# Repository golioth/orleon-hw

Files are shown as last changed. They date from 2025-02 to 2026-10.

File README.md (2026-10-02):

# Orleon

A small round battery-powered Bluetooth LE sensor board from Golioth, built
around the Nordic nRF52840 in WLCSP. Rev A.

Orleon was designed as part of Golioth's "Designing and Building an AirTag
Clone" webinar series (April 2025):
https://blog.golioth.io/designing-and-building-an-airtag-clone-a-new-series-from-golioth/

> **Status:** pre-release cleanup for open-hardware (OSHW) publication.
> Items marked **[UNKNOWN]** need confirmation before this README is final.

## Hardware summary (Rev A)

| Subsystem | Part / details | Notes |
|---|---|---|
| Main SoC  | Nordic nRF52840-CKAA-F-R | WLCSP package |
| IMU | ST LIS2DH12 | 3-axis accelerometer, I2C |
| Microphone| ST MP34DT05TR-A | PDM MEMS mic |
| Audio out | Raltron RDTE-4.000-3030-NS1 | electromagnetic transducer (buzzer) |
| BLE antenna | Taoglas WLA.04 | 2.4 GHz chip antenna |
| NFC | Taoglas FXC.24.A flex antenna | |
| Battery | CR2032 coin cell (HF1N holder) | |
| Board | round, ~22 mm diameter | [UNKNOWN] confirm exact diameter |

## Hardware status (Rev A)

Rev A was manufactured by JLCPCB but **never fully validated**. Two issues
were found before the design was set aside:

1. **BGA copper pour.** The copper fill under the nRF52840 WLCSP was filled
   improperly at the fab. Recommended rework: remove the copper pour under
   the BGA entirely and instead place vias on each ball down to the ground
   layer.
2. **Buttons.** The side-firing button style was not a good fit for this
   form factor.

**This design was superseded by [Phial](https://github.com/golioth/phial-hw)**
(nRF54L15 + nPM2100), which is the better starting point for new work —
though note that Phial has its own validation issues (see that repo's README
for current status).

## Design files

- KiCad 9 project (`orleon.*`).
- JLCPCB was used for Rev A fabrication; commit history notes their 3.5 mil
  trace/space clearance constraint drove via/pad rework (see commit
  `cd74782`).
- `input/` — local symbol/footprint/3D sources and reference art.
- `orleon.pretty/` — project footprints (including Golioth and Orleon logo art
  footprints).

## Manufacturing outputs

**[UNKNOWN / TODO]** Rev A gerber packages (`orleon-a-*.zip`) were generated
for JLCPCB but never committed (gitignored). A fabrication package (gerbers,
drill, pick-and-place, BOM, schematic PDF) should be attached to a GitHub
Release before publication.

## Firmware

Firmware lives in a separate repo: [golioth/orleon-fw](https://github.com/golioth/orleon-fw)
(currently private).

## License

Hardware in this repository is released under the **CERN Open Hardware
Licence v2 — Permissive (CERN-OHL-P)**. See [LICENSE](LICENSE).

Note: `input/art/` contains vendor reference images (JLCPCB stackup, Taoglas
antenna drawings) that are **not** covered by this license and may be replaced
with links before publication.

## Credits

Designed by Chris Gammell at Golioth.

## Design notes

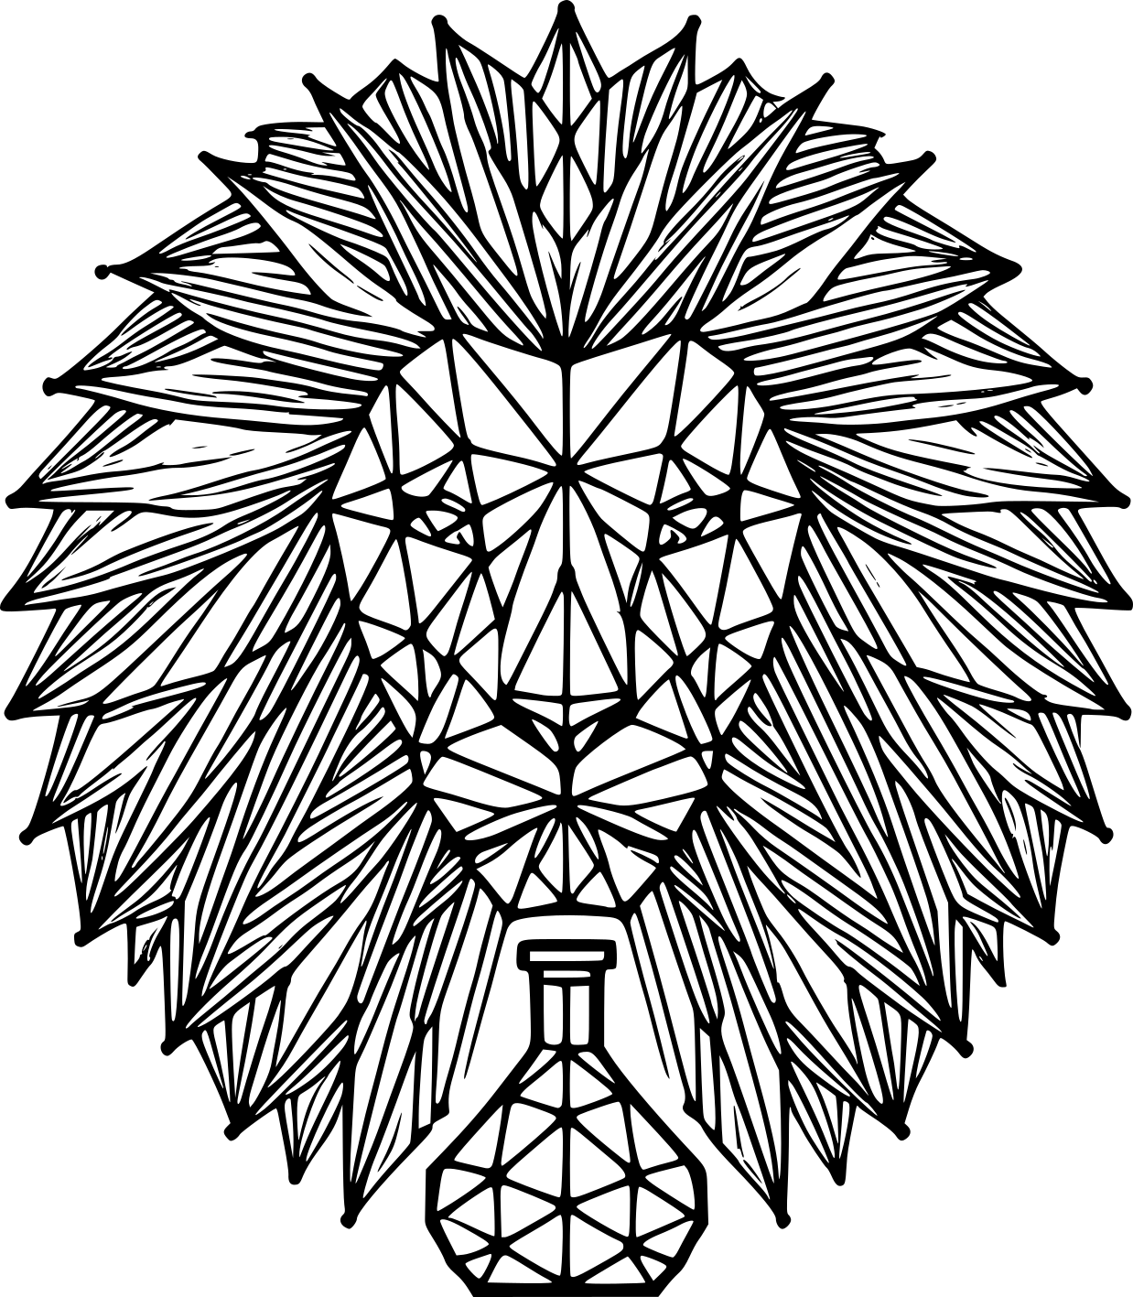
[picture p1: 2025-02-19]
input/art/orleon_36mm.png

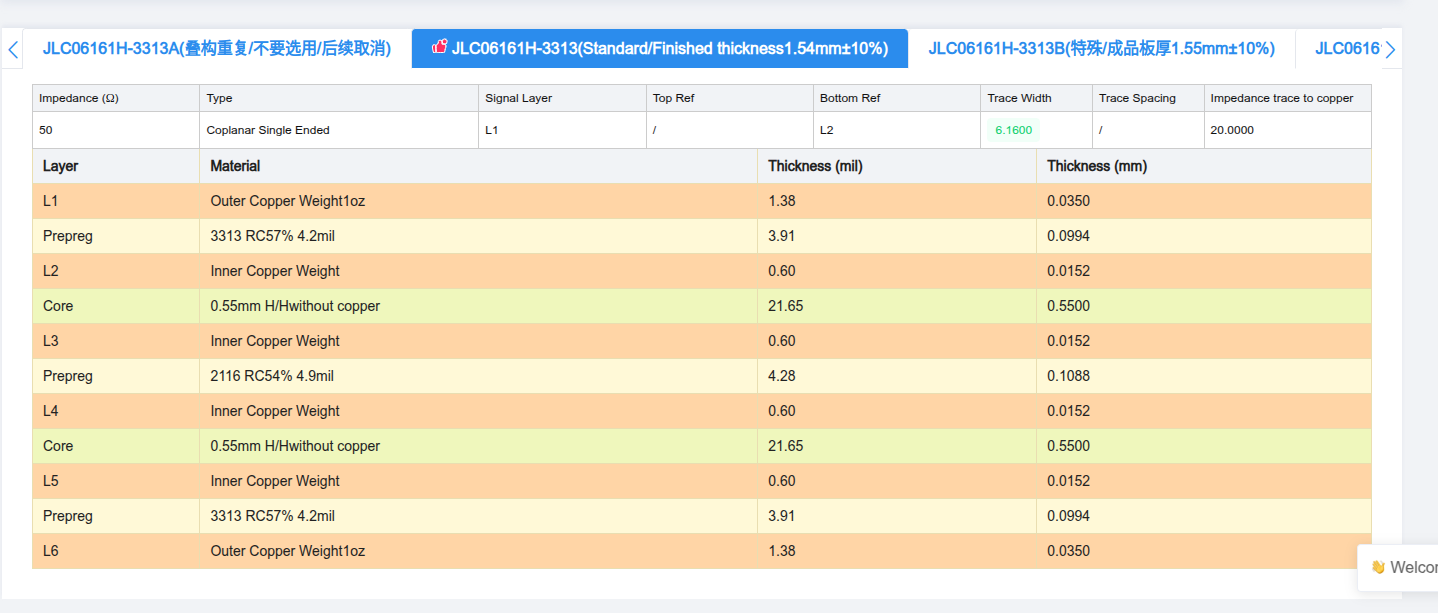
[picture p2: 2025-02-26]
input/art/JLC-0616.png

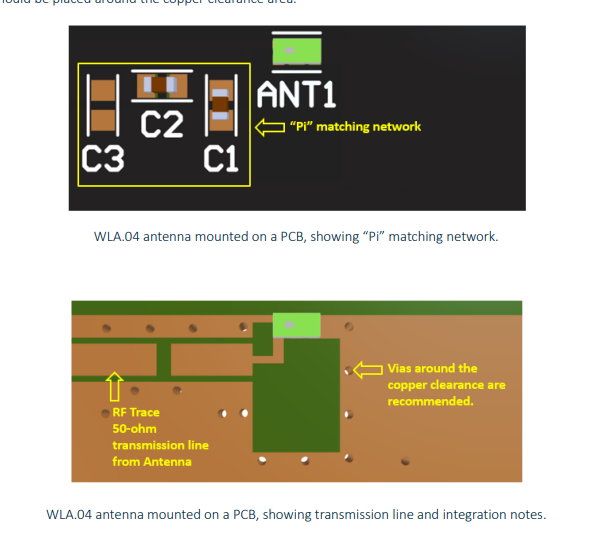
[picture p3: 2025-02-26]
input/art/WLA-04-Layout.png

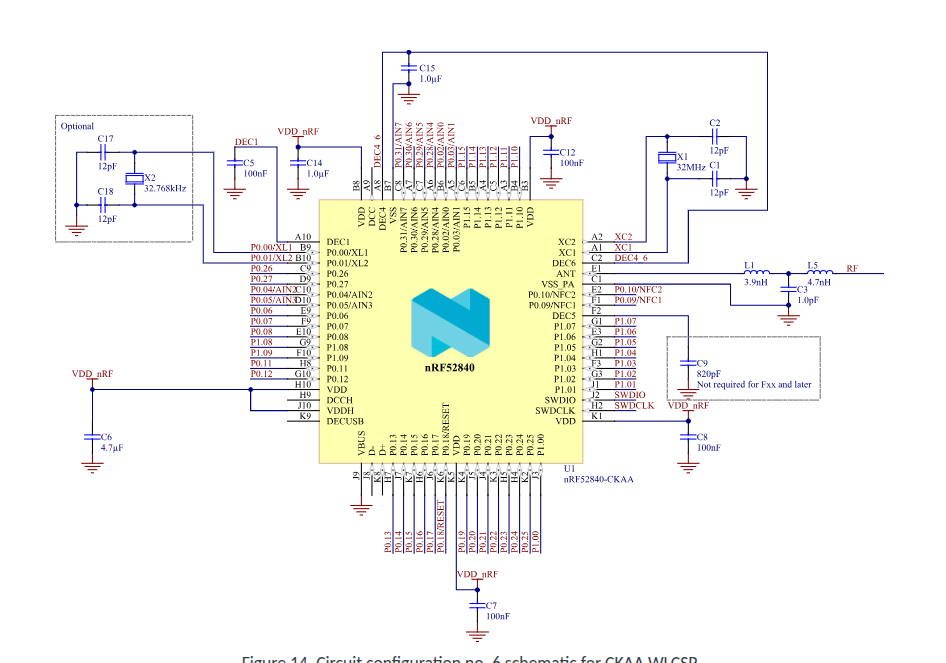
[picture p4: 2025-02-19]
input/art/battery_only_nrf52840_wlcsp.png

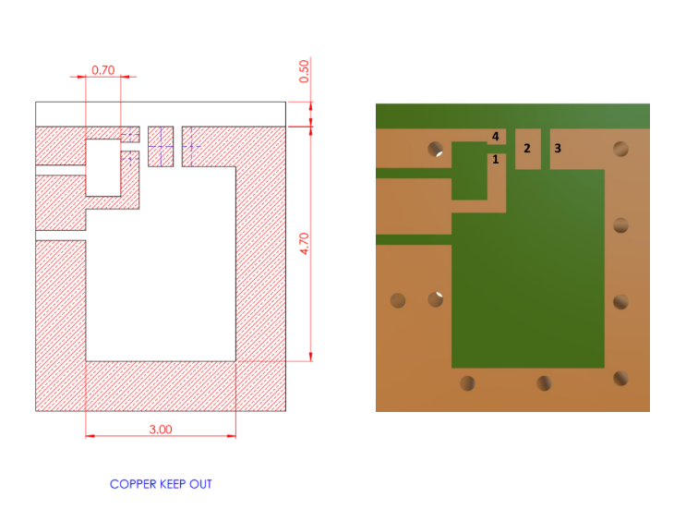
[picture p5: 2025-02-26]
input/art/WLA-04-Dimensions.png

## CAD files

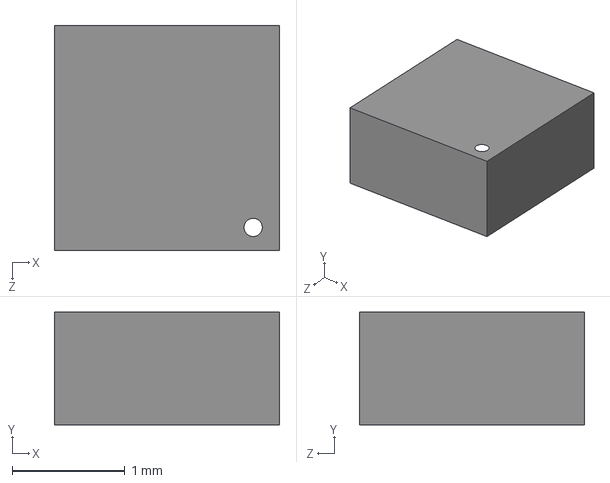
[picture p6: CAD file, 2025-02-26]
input/3d/LIS2DH12.step
2.00 x 1.00 x 2.00 mm

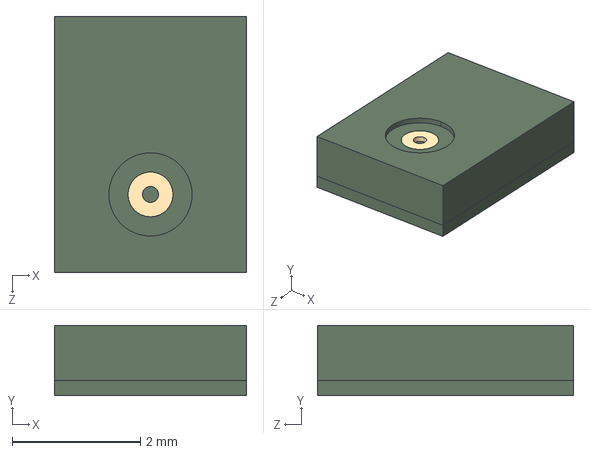
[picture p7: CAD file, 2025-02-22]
input/3d/MP34DT05TR-A.STEP
3.00 x 1.10 x 4.00 mm

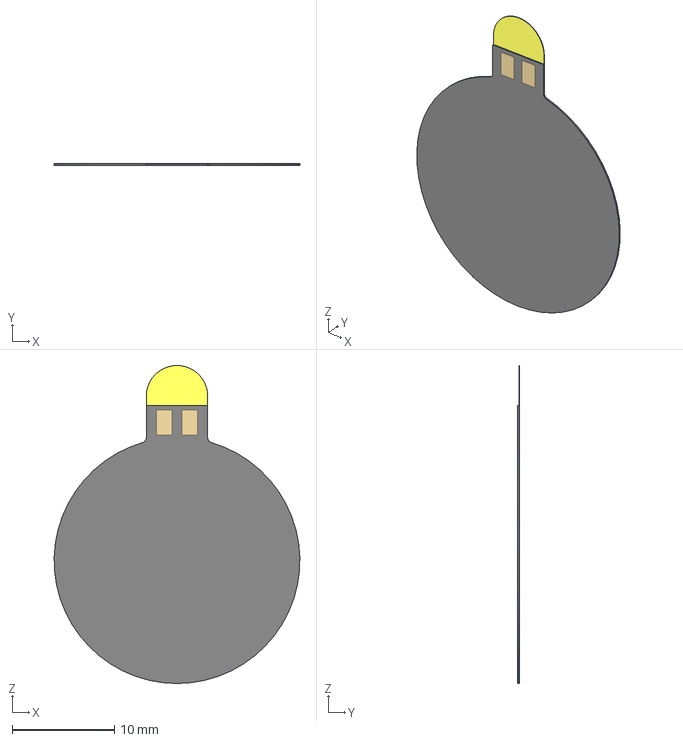
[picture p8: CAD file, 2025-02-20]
input/3d/FXC.24.A.stp
24.0 x 0.16 x 31.0 mm

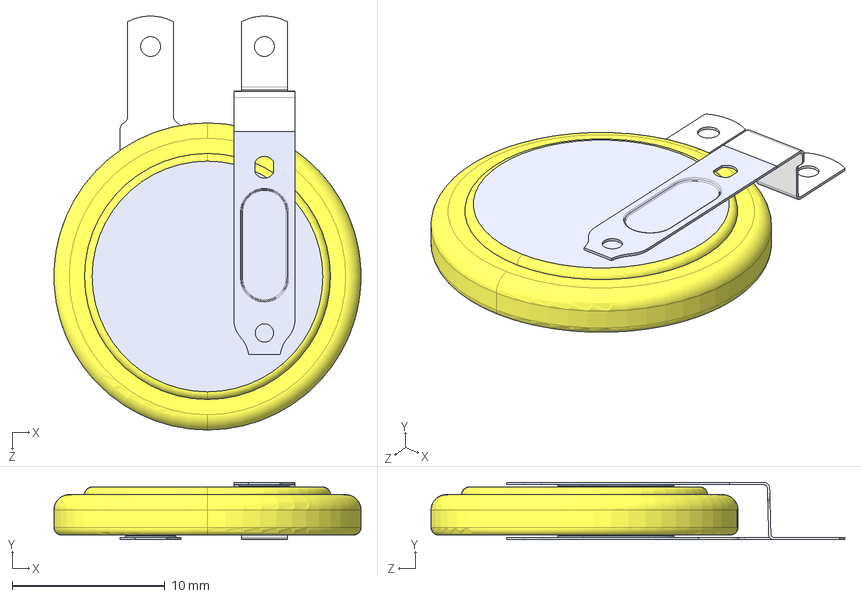
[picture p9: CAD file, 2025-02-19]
input/3d/F1N--3DModel-STEP-56544.STEP
20.1 x 3.75 x 27.1 mm

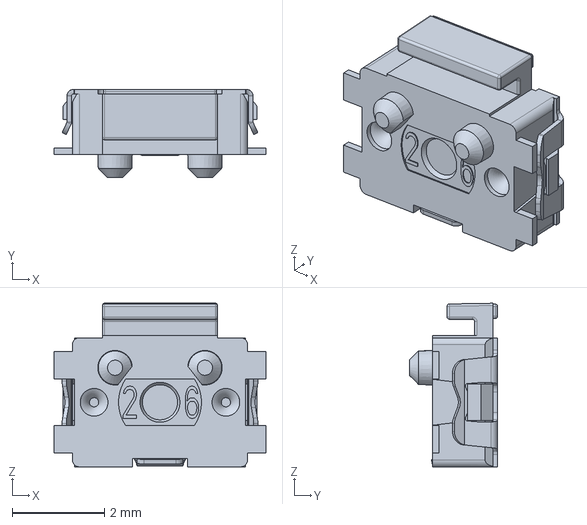
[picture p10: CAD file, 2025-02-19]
input/3d/KMS221GPLFS.stp
4.60 x 1.92 x 3.55 mm

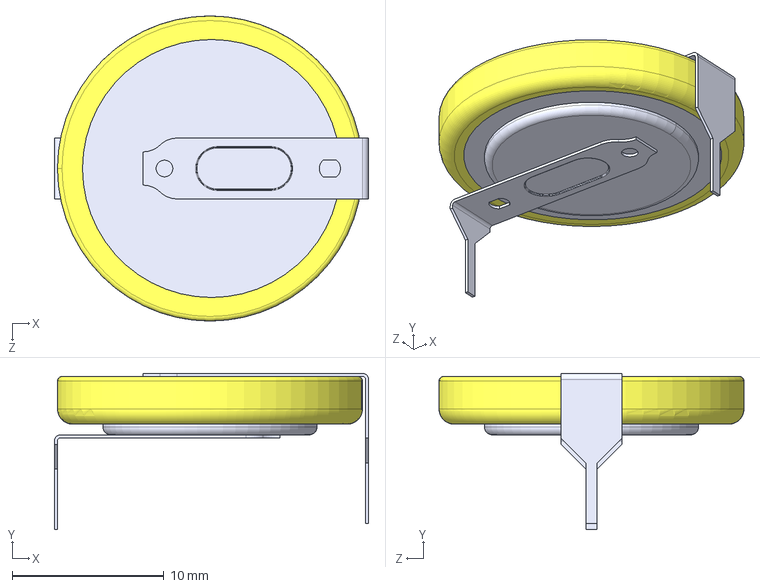
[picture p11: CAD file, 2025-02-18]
input/3d/CR-2032_HF1N.step
20.7 x 10.3 x 20.1 mm

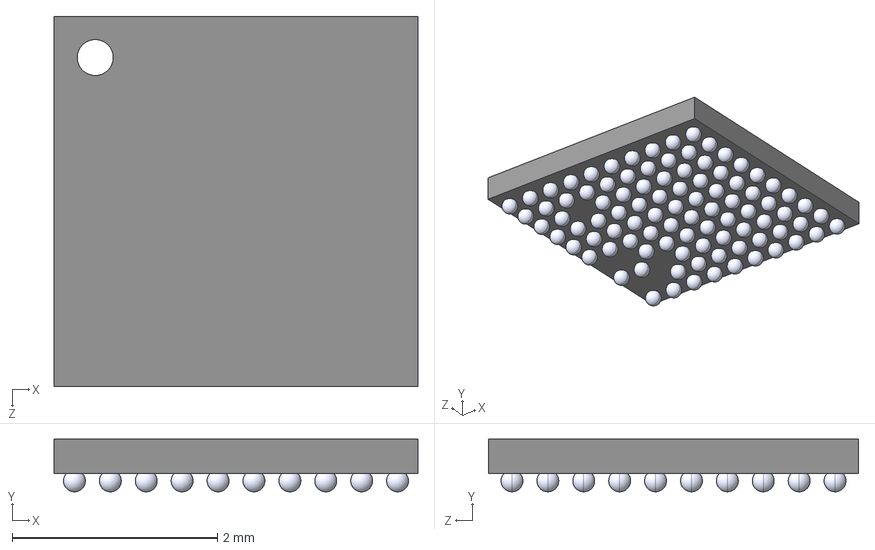
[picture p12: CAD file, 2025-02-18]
input/3d/NRF52840-CKAA-F-R.step
3.54 x 0.514 x 3.61 mm

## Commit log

2025-02-19 Shrunk board size to 32mm and added a bunch of new components/art
    [F1N--3DModel-STEP-56544.STEP, KMS221GPLFS.stp, orleon.kicad_pcb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]
2025-02-19 added new sensors and replaced 6 pin with 10 pin tc
    [orleon.kicad_pcb, orleon.kicad_sch]
2025-02-20 add nfc antenna landing pads
    [FXC.24.A.stp, orleon.kicad_pcb]
2025-02-21 Added buzzer, reoriented text to be radial, moved sensors/nfc
    [orleon.kicad_pcb, orleon.kicad_sch]
2025-02-21 add gitignore for KiCad files
2025-02-21 reorient LEDs to match clock face styling, add net names
    [orleon.kicad_pcb, orleon.kicad_sch]
2025-02-22 Adding more passives and hooking up signals in schematic
    [MP34DT05TR-A.STEP, orleon.kicad_pcb, orleon.kicad_sch]
2025-02-22 more connections, shifted components to put buzzer near battery and group all i2c components
    [orleon.kicad_pcb, orleon.kicad_sch]
2025-02-26 changed stackup and started routing RF
    [LIS2DH12.step, orleon.kicad_pcb, orleon.kicad_sch]
2025-02-26 reorient nrf52 to allow routing around RF section
    [orleon.kicad_pcb, orleon.kicad_sch]
2025-02-27 Escape from BGA, starring Work Fussell
    [orleon.kicad_pcb, orleon.kicad_sch]
2025-02-27 more routing updates, including pin swaps
    [orleon.kicad_pcb]
2025-02-28 all tracks routed, no DRC violations
    [orleon.kicad_pcb, orleon.kicad_sch]
2025-02-28 Re-routed tracks to test points on bottom, passed DRC
    [orleon.kicad_pcb, orleon.kicad_sch]
2025-02-28 Final board files sent as Rev A to JLC
2025-03-01 Board files orleon-a-202502281452.zip (rev A candidate) bounced back from JLC. Started moving vias and widening BGA pads for their process.
    [orleon.kicad_pcb]
2025-03-01 replaced all vias, started routing again
    [orleon.kicad_pcb, orleon.kicad_sch]
2025-03-02 Set trace to hole constraint to 0.15 mm and now dealing with the consequences
    [orleon.kicad_pcb, orleon.kicad_sch]
2025-03-02 all DRC passes with revised constraints. Sending gerbers orleon-a-202503021400.zip to JLC.
    [orleon.kicad_pcb, orleon.kicad_sch]
2025-03-02 Expanded keepout area for antenna to more closely match specsheet. Generated orleon-a-202503021426.zip for JLC
    [orleon.kicad_pcb]
2025-03-03 Found some errant 3 mil traces (extra charges). Fixed those and other small errors. Generated orleon-a-202503031636.zip for JLC
    [orleon.kicad_pcb]
2025-03-04 BGA footprint reverted to 0.2mm pads, had to fix again. Updated footprint and symbol to lock in changes. Modified silkscreen art. Generated orleon-a-202503041426.zip for JLC
    [orleon.kicad_pcb, orleon.kicad_sch]
2025-03-05 JLC claims traces aren't hitting their 3.5 mil clearance spec. Moved minimum up to 3.52 and fixing those errors. Generated orleon-a-202503042257.zip for JLC
    [orleon.kicad_pcb]
2025-03-22 add components to schematic
    [orleon.kicad_pcb, orleon.kicad_sch]
2026-10-02 OSHW release prep: docs, license, cleanup, footprint fix
2026-10-02 README: add Rev A validation history, BGA/button issues, Phial succession, series link
